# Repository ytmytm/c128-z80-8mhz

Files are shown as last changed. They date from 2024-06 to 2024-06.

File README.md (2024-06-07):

# C128 and 8MHz Z80

With a simple daughterboard, a GAL and a 74LS74 the Z80 in C128 can run at dot clock frequency (almost 8MHz) during its 1MHz phase of the system clock, effectively doubling the speed.

Basic benchmarks written in Turbo Pascal show that indeed it is about twice faster.

CP/M is visibly snappier, to the point of being usable.

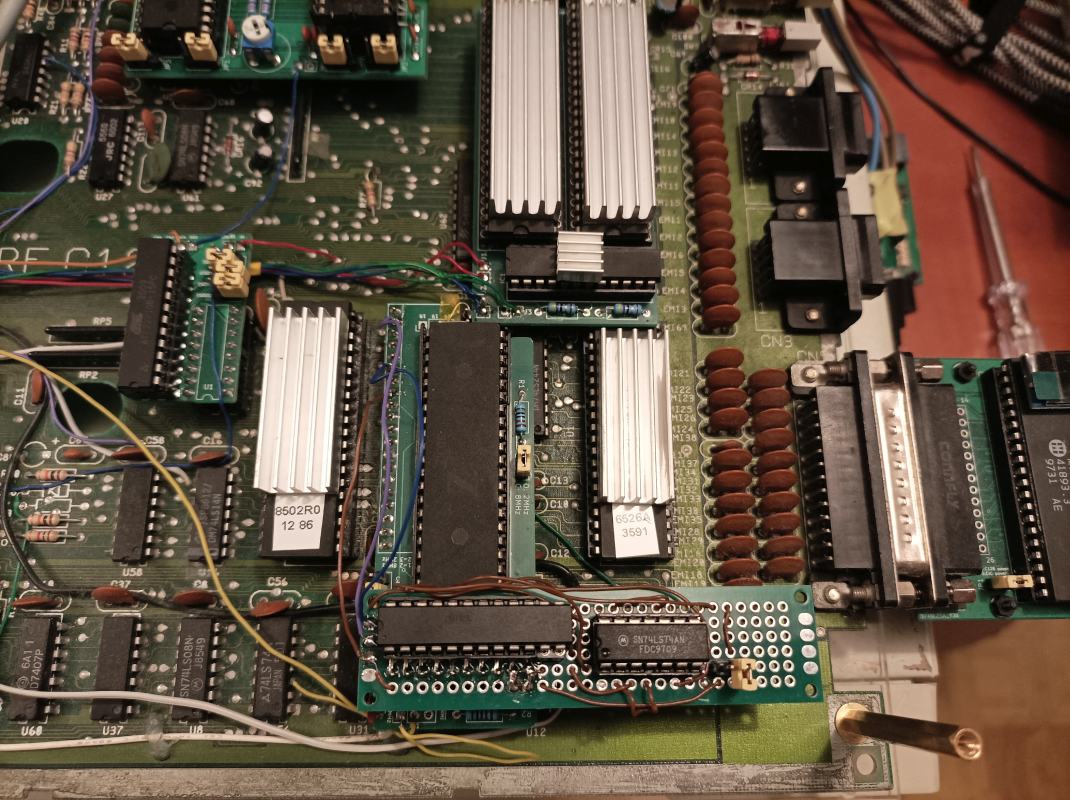
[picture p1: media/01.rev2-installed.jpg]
Tower of development daughterboards


This circuit works fine, during tests it was stable for several hours, busy with drawing fractals and calculating pi using Monte-Carlo method.

The CPU doesn't even get warm to the touch.

Disk I/O worked fine, as well as REU ram disk M: (emulated by UII+).

## BACKGROUND

There was a message sent to [cbm-hackers mailing list](https://www.softwolves.com/arkiv/cbm-hackers/7/7361.html) back in 2002, about a PCB for C128 that boosted Z80 to 8MHz

Unfortunately that device was not fully reverse-engineered and it seems that it was never mentioned again.

## PREPARING C128

I haven't tried to overclock the original Z80B, I replaced it some time ago by a Z84C0020 that uses much less energy.

Following modifications can be done using bending Z80 pins and soldering to the mainboard, but having a daughterboard will keep everything tidy.

We need to isolate `/WAIT` input (pin 24) from the mainboard because it is tied to `/NMI` there.
We will also disconnected from CPU the onboard `CLK` signal (pin 6).
We will use it as an GAL input to have an option of switching between the original clock (4MHz half of the time) and fast mode (8MHz half of the time).
The new `CLK` will be generated by GAL. We will also use few other lines from Z80 as GAL inputs.

We need two more inputs not available on the Z80 chip/Z80 socket. We want `DOT CLOCK` from the expansion port (pin 6) and the system clock 1MHz signal
(called `CLK1MHZ` below and `D1MHZ` on C128 schematic) from U12 (pin 11).

## OPERATION

This is the normal timing of Z80 in C128. During system clock `CLK1MHZ` low phase VIC generates two clock ticks for Z80.

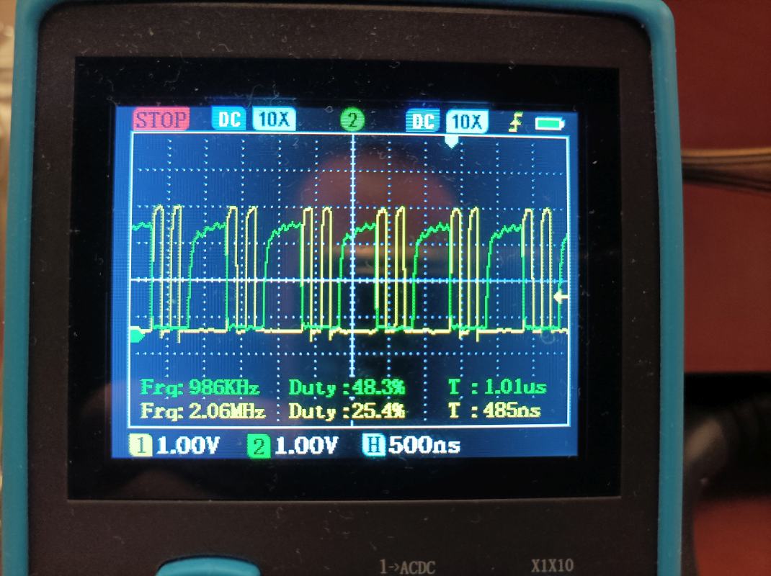
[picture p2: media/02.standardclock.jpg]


We use `DOT CLOCK` instead to pass four ticks.

Whenever Z80 wants to read or write to/from memory or I/O we have to stop it until the start of the next 1MHz clock low phase.

Latched data from 74LS74 will hold the `/WAIT` line low until the end of current low phase of `CLK1MHZ` (Z80 turn).
During the following high phase (VIC's turn) 74LS74 will stay in reset and release `WAIT` to inactive (high) state, but during that time we will not output any clock pulses - just like in the original setup.

I had to add a case to `CLKOUT` to handle memory writes. Waitstate is not enough, the CPU had to be really stopped. That's not an issue for reads because they are buffered with U12.

Here is the effect - for two clocks Z80 was running at 1MHz because of memory write, then picked up the speed:

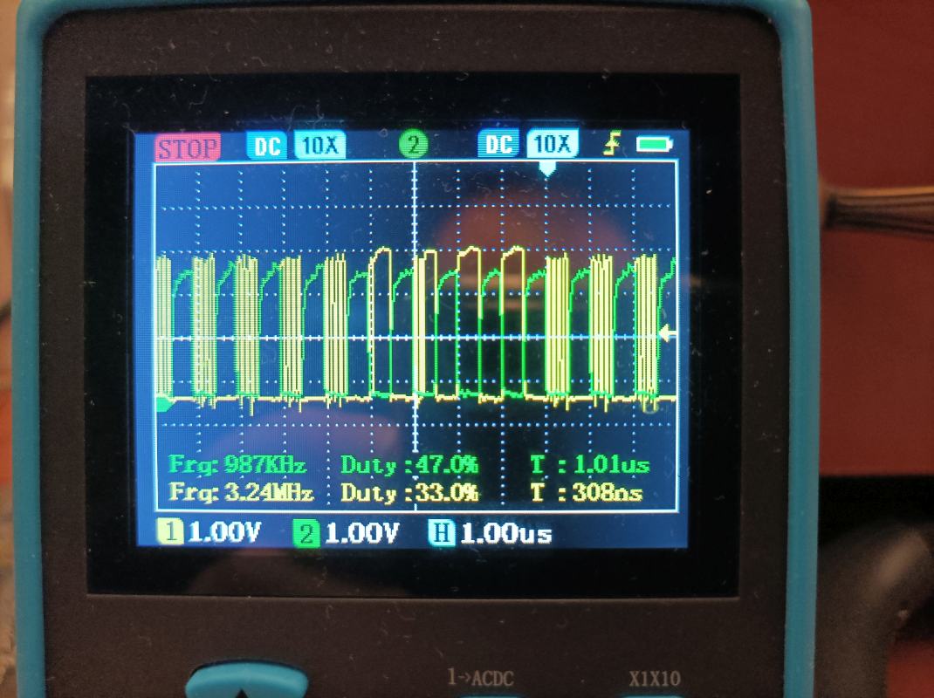
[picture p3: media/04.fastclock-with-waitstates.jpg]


## CIRCUIT

The Kicad project is in [z80-dotclock-gal-and-latch/](z80-dotclock-gal-and-latch) folder.

Schematic is also [available in PDF form](z80-dotclock-gal-and-latch/plots/z80-dot-gal.pdf).

## PCB

Gerber files generated from PCB project that should fit C128 and C128DCR are in  [z80-dotclock-gal-and-latch/gerbers/](z80-dotclock-gal-and-latch/gerbers) folder.

## LOGIC EQUATIONS

PLD file to be used with WinCUPL to generate JED file for programming GAL is available in two versions:

- for 22V10 in [z80-dotclock-gal-and-latch/gal22v10/](z80-dotclock-gal-and-latch/gal22v10/)
- for 16V8 in [z80-dotclock-gal-and-latch/gal6v8/](z80-dotclock-gal-and-latch/gal16v8/)

You will find there all the files generated by WinCUPL, including JED files ready to be flased to GAL devices.

They differ only in pin numbering. I just happened to have an ATF22V10 available.
The circuit is ready for both options - just align pin 1 of 16V8 with pin 1 of the socket.

### 74LS74 and bus timing

Here is how it is supposed to work:

0. VIC cycle phase starts, latch is in reset state, latch `D` input is
   constant `1`, but due to reset `Q` output is `0` and negated `/Q` is `1`; Z80 is
   stopped as its clock is held low
1. Z80 cycle phase starts, latch goes out of reset, `/Q` output = `WAITLATCH`
   stays `1`, Z80 sees that as inactive `/WAIT` and runs program, without bus
   access requests `WAITTRIGGER` stays `0`
2. Z80 wants to access the bus, `WAITTRIGGER` will rise to `1`; this will cause
   latch D input connected to `1` be copied to the output, so `/Q` becomes `0`, Z80
   will see that as an active `/WAIT` and will stop
3. This state will not change until start of the next VIC cycle phase
4. VIC cycle phase starts, latch is reset - will set latch `/Q` to `1`, so for
   Z80 `/WAIT` now becomes inactive; but Z80 won't run because during this
   half-cycle the CPU clock signal is not passed at all
5. Z80 cycle phase starts, it can continue because after latch reset `/WAIT`
   is inactive; Z80 accesses the bus so `WAITTRIGGER` stays `1` until Z80 gets
   what it needs from data lines - then it goes back to `0`

The idea of this is that during Z80 clock phase when `WAITTRIGGER` goes from
inactive to active we can latch `/WAIT` line low to hold it low at least
until the start of VIC cycle.

We release it before/at the start of Z80 cycle it so `/WAIT` becomes high
again - even though the latch trigger condition is still active.

### CLKOUT
The simplest way to handle CLKOUT I did was:
```
  CLKOUT = !DOTCLK & !CLK1MHZ;
```
C128 started fine, but CP/M wouldn't boot. With pieces of Z80 code I was able to confirm that this works for I/O reads and writes but only memory reads.
Memory writes never happened, hence the special case with `MREQ & WR`. 

## 16MHZ?

I tried using the 16MHz clock signal from VDC (pin 2) instead of dot clock.

The C128 will start, but CP/M won't boot. However all my simple tests passed.
I suspect that memory access is still an issue and some of the memory writes fail.

A possible reason is that exact 16MHz signal is not a true double of the dot clock, which depends on PAL/NTSC.

If this is the reason, then one solution could be to [double the dot clock using MAX9010](https://www.analog.com/en/resources/design-notes/simple-circuit-doubles-input-frequency.html).
This idea was [already mentioned on Reddit](https://www.reddit.com/r/c128/comments/9judf7/z80_possible_clockdoubling_mitigation_against/), but that circuit would never work.
But it depends on specific values of R/C pair.

Using a part [specifically designed for that purpose - ICS501](https://www.renesas.com/us/en/document/dst/501-datasheet) seems more reliable.

## OPEN QUESTIONS

1) How can we keep it simple but run at full speed all the time and stall only on memory and I/O access? It's not clear if the device mentioned in 2002 was really working at 8MHz all the time or just during Z80's turn.

2) Since I already used ATF22V10 which has asynchronous reset for registers, it should be possible to get rid of 74LS74 with different assignment of pin 1 (GAL CLK input). I wasn't able to do it.
   I'm probably doing something wrong - messing up high/low vs active/inactive or my CUPL skills are lacking (they are).

3) What is the problem with 16MHz clock? Maybe it should be created by doubling the dot clock to keep things in sync? (No need to bother if (1) is possible).

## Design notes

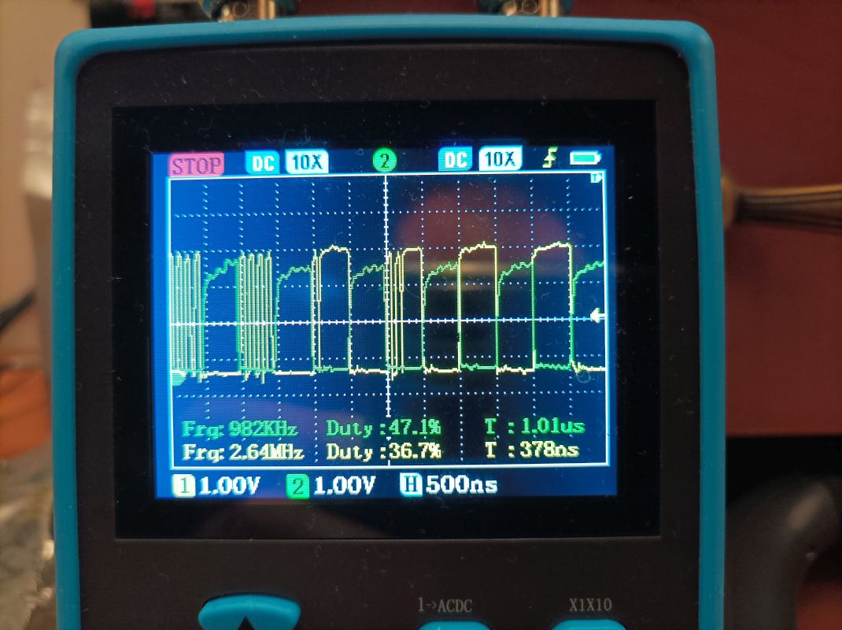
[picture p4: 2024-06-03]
media/03.fastclock-with-waitstates.jpg

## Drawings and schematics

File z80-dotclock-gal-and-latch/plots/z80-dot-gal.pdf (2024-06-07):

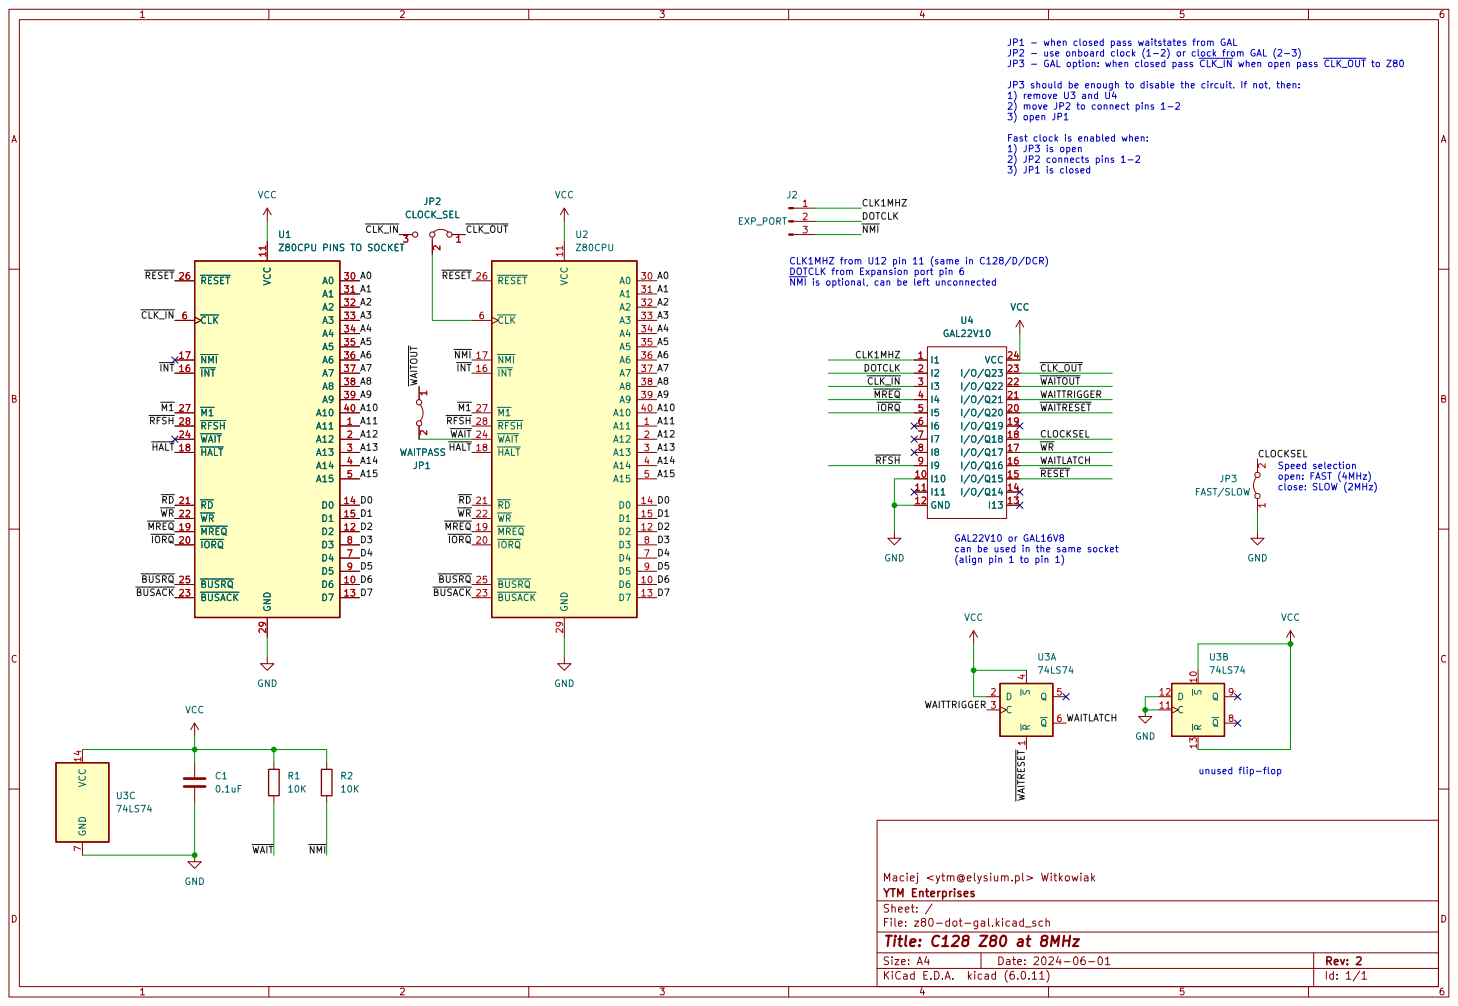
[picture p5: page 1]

2) move JP2 to connect pins 1-2
3) open JP1 Fast clock is enabled when: 1) JP3 is open

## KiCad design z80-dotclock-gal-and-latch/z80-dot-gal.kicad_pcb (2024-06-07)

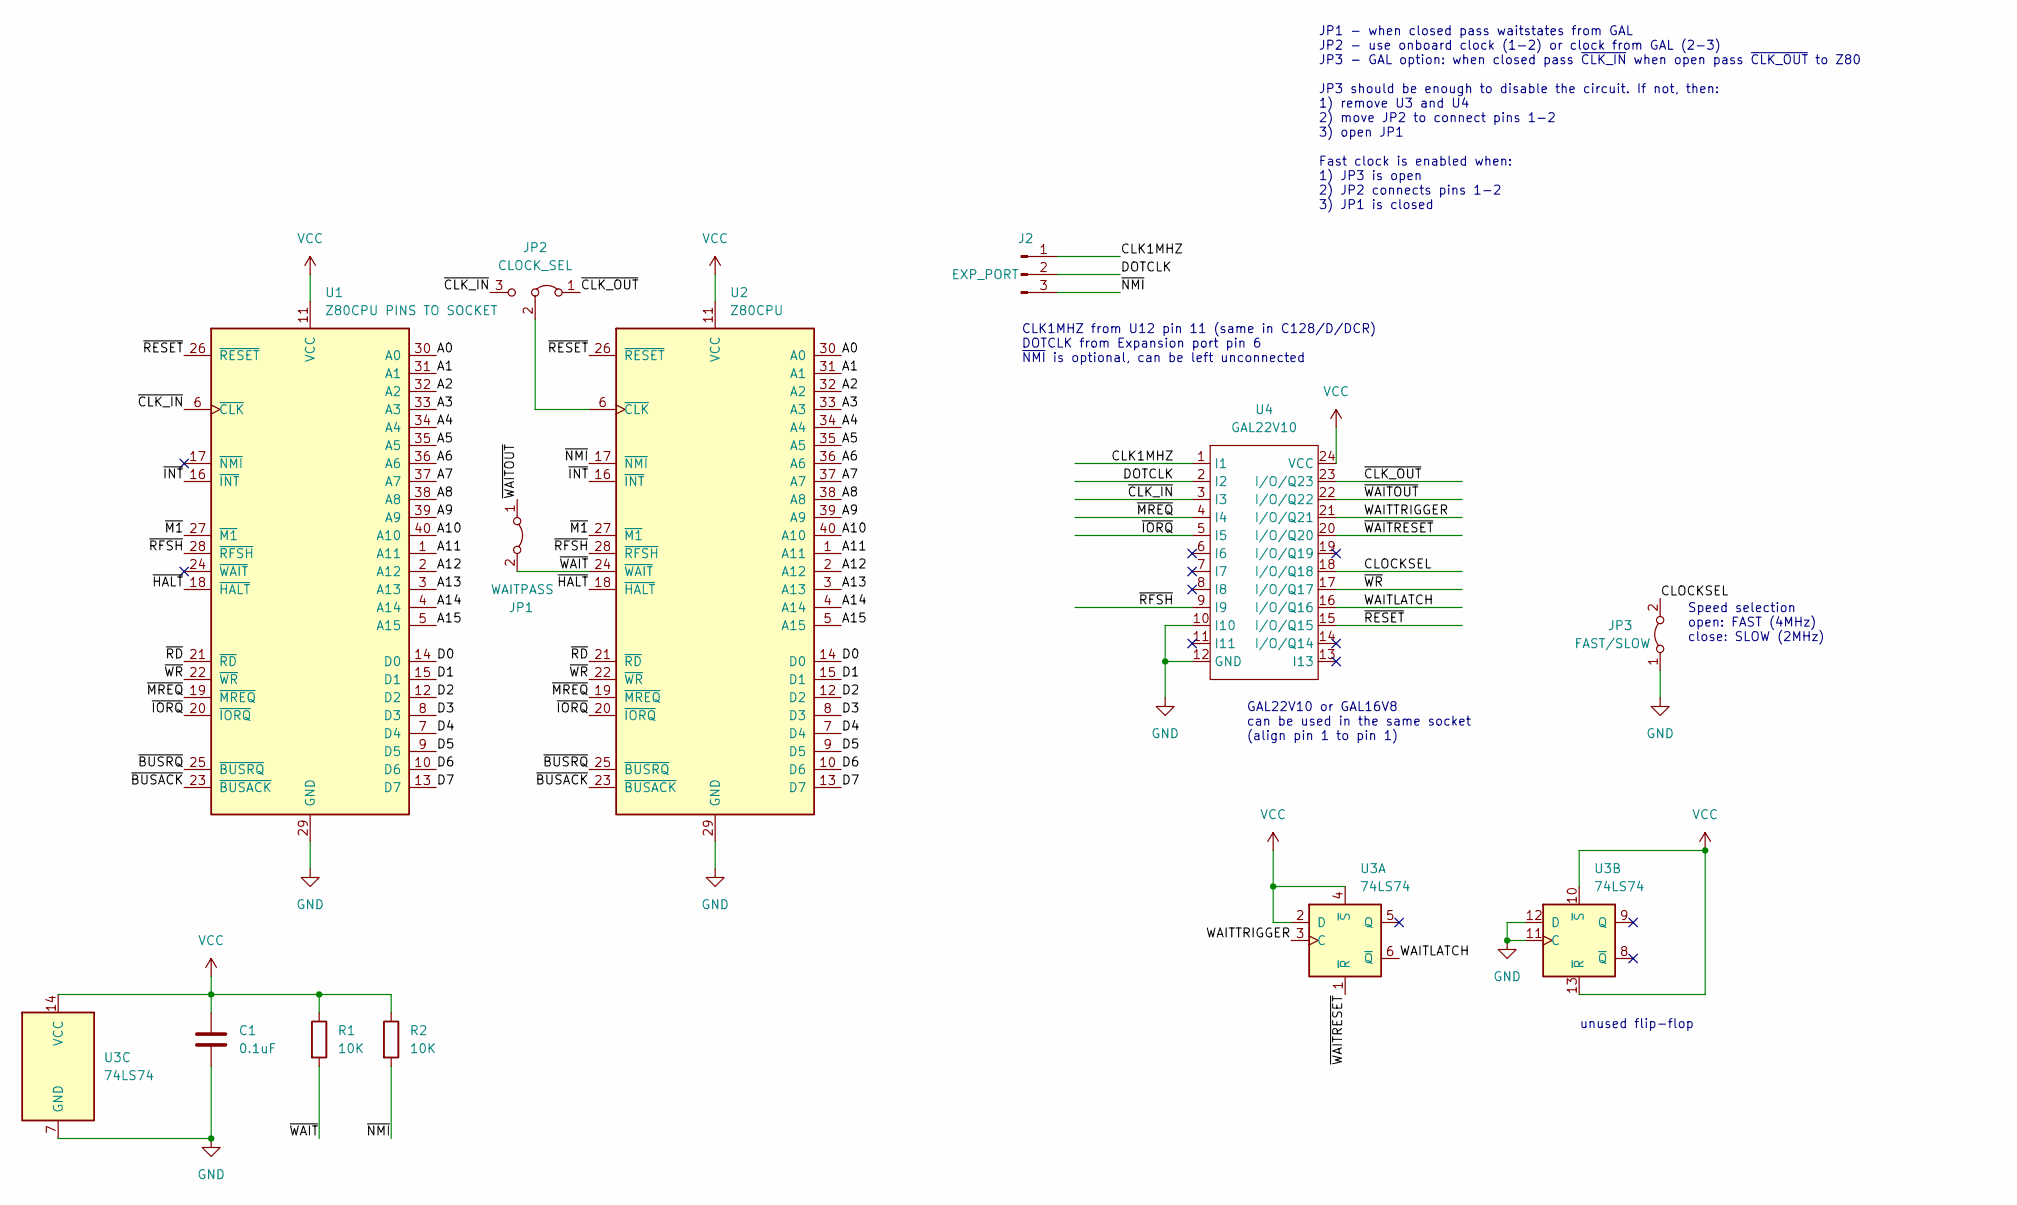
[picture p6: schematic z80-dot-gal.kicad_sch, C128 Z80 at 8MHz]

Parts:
C1: 0.1uF; C_Disc_D8.0mm_W2.5mm_P5.00mm
J2: EXP_PORT; PinHeader_1x03_P2.54mm_Vertical
JP1: WAITPASS; PinHeader_1x02_P2.54mm_Vertical
JP2: CLOCK_SEL; PinHeader_1x03_P2.54mm_Vertical
JP3: FAST/SLOW; PinHeader_1x02_P2.54mm_Vertical
R1, R2: 10K; R_Axial_DIN0207_L6.3mm_D2.5mm_P10.16mm_Horizontal
U1: Z80CPU PINS TO SOCKET; DIP-40_W15.24mm_Socket_LongPads
U2: Z80CPU; DIP-40_W15.24mm_Socket_LongPads
U3: 74LS74; DIP-14_W7.62mm_Socket
U4: GAL22V10; DIP-24_W7.62mm_Socket

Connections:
/A0: U1.30 (A0), U2.30 (A0)
/A1: U1.31 (A1), U2.31 (A1)
/A2: U1.32 (A2), U2.32 (A2)
/A3: U1.33 (A3), U2.33 (A3)
/A4: U1.34 (A4), U2.34 (A4)
/A5: U1.35 (A5), U2.35 (A5)
/A6: U1.36 (A6), U2.36 (A6)
/A7: U1.37 (A7), U2.37 (A7)
/A8: U1.38 (A8), U2.38 (A8)
/A9: U1.39 (A9), U2.39 (A9)
/A10: U1.40 (A10), U2.40 (A10)
/A11: U1.1 (A11), U2.1 (A11)
/A12: U1.2 (A12), U2.2 (A12)
/A13: U1.3 (A13), U2.3 (A13)
/A14: U1.4 (A14), U2.4 (A14)
/A15: U1.5 (A15), U2.5 (A15)
/CLK1MHZ: J2.1, U4.1 (I1)
/CLOCKSEL: JP3.2 (B), U4.18 (I/O/Q18)
/D0: U1.14 (D0), U2.14 (D0)
/D1: U1.15 (D1), U2.15 (D1)
/D2: U1.12 (D2), U2.12 (D2)
/D3: U1.8 (D3), U2.8 (D3)
/D4: U1.7 (D4), U2.7 (D4)
/D5: U1.9 (D5), U2.9 (D5)
/D6: U1.10 (D6), U2.10 (D6)
/D7: U1.13 (D7), U2.13 (D7)
/DOTCLK: J2.2, U4.2 (I2)
/WAITLATCH: U3.6 (~Q), U4.16 (I/O/Q16)
/WAITTRIGGER: U3.3 (C), U4.21 (I/O/Q21)
/~BUSACK: U1.23 (~BUSACK), U2.23 (~BUSACK)
/~BUSRQ: U1.25 (~BUSRQ), U2.25 (~BUSRQ)
/~CLK_IN: JP2.3 (B), U1.6 (~CLK), U4.3 (I3)
/~CLK_OUT: JP2.1 (A), U4.23 (I/O/Q23)
/~HALT: U1.18 (~HALT), U2.18 (~HALT)
/~INT: U1.16 (~INT), U2.16 (~INT)
/~IORQ: U1.20 (~IORQ), U2.20 (~IORQ), U4.5 (I5)
/~M1: U1.27 (~M1), U2.27 (~M1)
/~MREQ: U1.19 (~MREQ), U2.19 (~MREQ), U4.4 (I4)
/~NMI: J2.3, R2.2, U2.17 (~NMI)
/~RD: U1.21 (~RD), U2.21 (~RD)
/~RESET: U1.26 (~RESET), U2.26 (~RESET), U4.15 (I/O/Q15)
/~RFSH: U1.28 (~RFSH), U2.28 (~RFSH), U4.9 (I9)
/~WAITOUT: JP1.1 (A), U4.22 (I/O/Q22)
/~WAITRESET: U3.1 (~R), U4.20 (I/O/Q20)
/~WAIT: JP1.2 (B), R1.2, U2.24 (~WAIT)
/~WR: U1.22 (~WR), U2.22 (~WR), U4.17 (I/O/Q17)
GND: C1.2, JP3.1 (A), U1.29 (GND), U2.29 (GND), U3.7 (GND), U3.11 (C), U3.12 (D), U4.10 (I10), U4.12 (GND)
unnamed: JP2.2 (C), U2.6 (~CLK)
VCC: C1.1, R1.1, R2.1, U1.11 (VCC), U2.11 (VCC), U3.2 (D), U3.4 (~S), U3.10 (~S), U3.13 (~R), U3.14 (VCC), U4.24 (VCC)

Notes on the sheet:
GAL22V10 or GAL16V8 can be used in the same socket (align pin 1 to pin 1)
CLK1MHZ from U12 pin 11 (same in C128/D/DCR) DOTCLK from Expansion port pin 6 ~{NMI} is optional, can be left unconnected
JP1 - when closed pass waitstates from GAL JP2 - use onboard clock (1-2) or clock from GAL (2-3) JP3 - GAL option: when closed pass ~{CLK_IN} when open pass ~{CLK_OUT} to Z80 JP3 should be enough to disable the circuit. If not, then: 1) remove U3 and U4 2) move JP2 to connect pins 1-2 3) open JP1 F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
Speed selection open: FAST (4MHz) close: SLOW (2MHz)
unused flip-flop

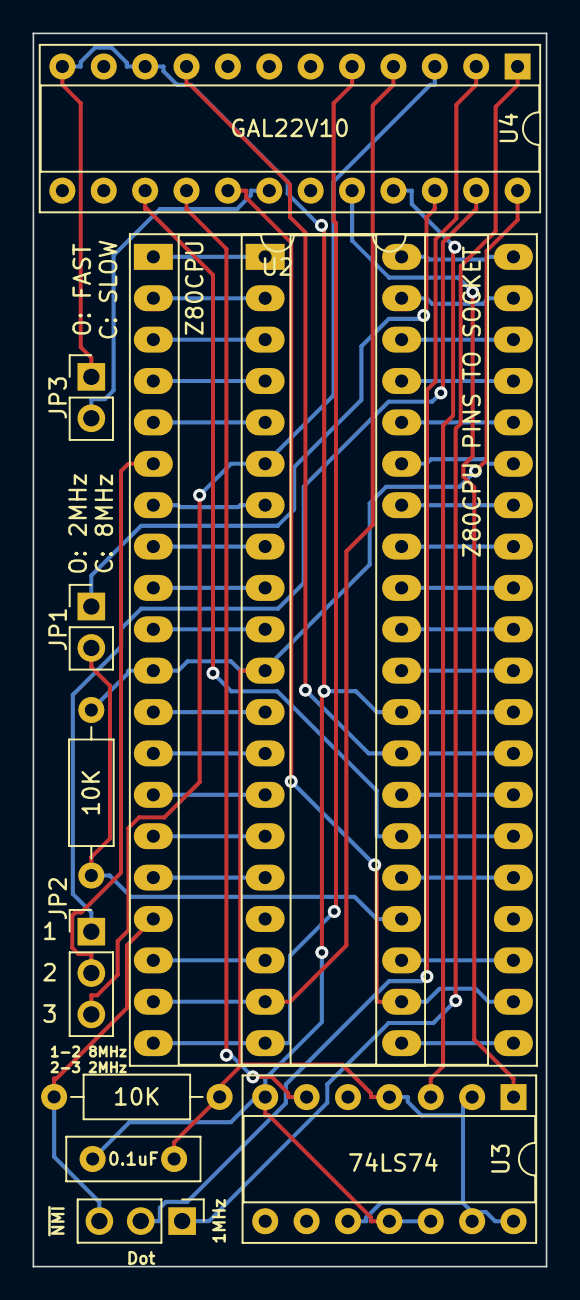
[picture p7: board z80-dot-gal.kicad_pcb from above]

Board: 2 copper layers, 31.5 x 75.7 mm, 11 parts (0 on the bottom side), 49 nets.

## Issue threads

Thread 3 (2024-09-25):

Support Z80 part with instruction cache

0x444454, 2024-09-25:
Memory access is still a bottleneck.
Consider using a more modern CPU (e.g. Z280) which adds instruction and data cache, plus several other nice features.
See also here:

https://github.com/Konamiman/Z280TechnicalManual/blob/master/A-Z80_Z280_Compatibility.md

ytmytm, 2024-09-27:
Interesting, I didn't know about this part. Thanks!

I'll put it on my to do list to obtain it to see if it can be used as a drop-in replacement here.

lgblgblgb, 2024-09-27:
I'm  not sure about Z280, but for Z180, it's problematic as it does not implement all Z80 things, for example the "undocumented" opcodes like using the IX register as two 8 bit ones (IXL and IXH) + same for IY, and possible other stuffs. Also, there can be a problem, that more modern Z80-compatible CPUs/MCUs have on-chip peripherals which uses the I/O space partly and I/O ops are not even routed then to the outside bus :( For example the "very modern" eZ80 would be nice to use in places where I have a Z80 but there for example very ports 0x00...0xFF are used by the chip itself :( So usually is a big no-no to use existing designs then, where Z80 was used before :( But I would be very much interested to know if there is a good candidate to replace existing Z80 with a more modern parts which do not have problems like I mentioned ...

0x444454, 2024-09-27:
Indeed, the eZ80 and other modern Z80 variants may be tricky to adapt, but most importantly they don’t have cache memory so even if they are more efficient at the same clock frequency, they will still be impacted by the C128 memory bottleneck.

I am not an expert on the Z280, so I am not sure how feasible/easy it is to use it as a replacement.
While the Z280 can be configured to work on a classic 8-bit Z80 bus (“OPT” pin tied to GND), it still multiplexes (AD0..AD7), so there is at least some demultiplexing needed.

lgblgblgb, 2024-09-28:
Btw eZ80 - IMHO/IIRC - also has a Z80 bus mode, I would more worrying on other details as well (and yes, eZ80 doesn't have a cache, in fact one of the design factors was that SRAM is cheaper/faster than ever before so even no need for that ... unlike with some older though newer than Z80-family parts).

ytmytm, 2024-09-28:
Perhaps such Z80 replacement should be isolated from C128 bus until access is needed. Something like this project for C64: https://github.com/kneehighspy/Z80-Card_for_Commodore_C64
just not in form of a cartridge, but something that would be plugged into Z80 socket on C128's mainboard.

ytmytm, 2024-11-02:
Here is an early attempt. The whole project is attached. The GAL code is exactly the same as here.

[z280-dot-gal-latch.zip](https://github.com/user-attachments/files/17608436/z280-dot-gal-latch.zip)

Today I ran some tests on this daughterboard.

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

Unfortunately it doesn't work as it should yet - the computer doesn't enter C128 mode.
The test program that I put into diagnostic ROM (offset $5000 within 32K Keranl ROM, that appears at $0000 for Z80 after reset).
The program just increases border colour in a loop:

```
	LD BC, $D020
	LD A, 0
LOOP:	OUT (C), A
	INC A
	JR LOOP
```

I get different patterns at:

-  normal clock (2 cycles / within low phase of 1 MHz tick)
-  at dot clock speed (4 cycles)
-  at doubled dot clock (8 cycles)
-  even at quadrupled (16 cycles)

With faster clocks I have to reset mutliple times until correct startup. With normal clock it works almost every time.

Once it starts it's completely stable, won't lock up randomly.

I also get different patterns with Z280 memory cache enabled, so I suppose that feature works too:

```
	LD C, $12	; cache control register
	LD L, 00001000b ; enable data cache, enable code cache
	.db 0edh,6eh ; ldctl	(c),hl
```

I gather from this that:

- the circuit in general works and I got the shared address/data bus right
- reading code from ROM works
- outputing data to I/O works

Project files are attached here, they need two modifications for the next revision:

- U2/U6 74'373 `/OE` (pin 1) has to be tied to `GND`, connecting it to `CLK1MHZ` was not a good idea (as suspected); without `/OE` another part can be used (like in ZZ80RC project)
- JP5: clkfast/clkout jumper is useless, should be connected to `CLKOUT` at all times

A Z80 diagnostic code that doesn't use RAM would be nice. Right now I can't enter C128 mode, so I have no way of testing memory access without writing some more elaborate Z80 code and I'm not Z80 coder.

References:

- https://github.com/wwarthen/CPU280/
- https://github.com/Plasmode/ZZ80RC

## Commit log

2024-06-01 initial import
    [z80-dot-gal.kicad_pcb, z80-dot-gal.kicad_sch]
2024-06-03 Schematic revision v2, without PCB: - remove test pads - remove unused connections to GAL pins 6-8 - add J3 and lots of descriptions - add required connects to /WR, /RESET, /RFSH - make GAL socket co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
    [z80-dot-gal.kicad_pcb, z80-dot-gal.kicad_sch]
2024-06-03 updated comments and pin assignment to make the most of V1 PCB compatible with GAL16V8 (renumber output pins)
2024-06-03 schematic v2 plot
2024-06-03 correct descriptions
    [z80-dot-gal.kicad_sch]
2024-06-07 gal16v8 pin numbers
2024-06-07 C128D/DCR PCB project (without cutout for 256k MMU expansion)
    [z80-dot-gal-B_Cu.gbl, z80-dot-gal-B_Mask.gbs, z80-dot-gal-B_Paste.gbp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]
2024-06-19 rev 2.1 development board with ICS501 clock multiplier and reordered GAL inputs
2024-06-19 update to new board revision, no change with latch yet
2024-07-14 updated for pins assigned according to v2.1 PCB
2024-10-09 Z280 option; parts from https://github.com/flypie/Z80-CPU-for-KiCAD.git based on https://github.com/Plasmode/ZZ80RC
2026-02-09 Z280 board with CPLD for more testing options AND Z80 fallback (to regain control for 6502) - too big for C128DCR, can only fit in C128D w/o a case - no CPLD firmware yet
